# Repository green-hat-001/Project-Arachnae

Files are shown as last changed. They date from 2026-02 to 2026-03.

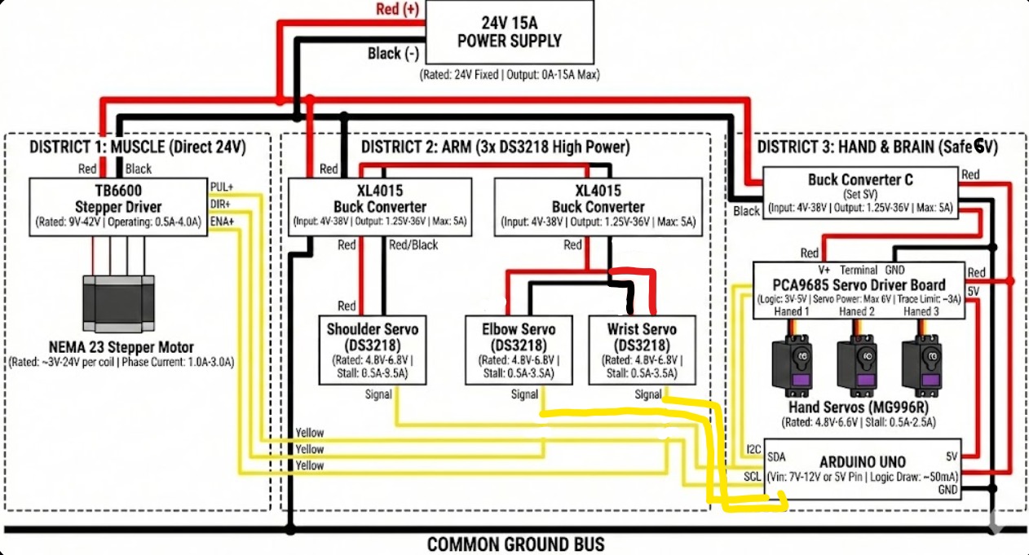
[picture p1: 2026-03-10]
Schematic.jpeg

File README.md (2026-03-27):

# Project-Arachnae
A semi-opensource prosthetic aimed at making prosthetics more usable and accessable to people with a tight budget and/or in developing countries. This project was started as passion project to experiment on a freind of mine who doesn't have an arm. Then as the project developed it became a vision to make these prosthetic more accessable and more usable compared to the super expensive ones out there that dont really have much functionalty built into them. 

The main step file has been compressed due to its size of CAD model. Below is the link to veiw the file in the browser as again the file is way too big to upload to github. You can download .f3d or any other file types from the below link.
-> https://a360.co/4daP7HM

**How to use:**
- The user will wear a backplate that houses the arm. When the user turns on the arm a preloaded script automatically runs. Then the user can voice out commands like, "Top right cup" and the ML model built into the arm will use the camera mounted on the hand to search for a cup in the "top right" of the user. The camera also serves as a method for the hand to determine the optimal grip for the object.

- 1770411682987 (1)

The below will explain how the arm works, for greater detail contact me via the email (gal1le02620@gmail.com)

---

## How It Works: Technical Architecture

Project Arachnae leverages accessible hardware and software to create a highly functional, low-cost bionic arm. The system is broken down into three main categories: mechanical design, hardware, and the control system.

### 1. Mechanical Design & Manufacturing

To keep costs low and ensure the prosthetic is accessible globally, the structural components are fully 3D printable. 
* **Modeling:** The components are designed using CAD software like Fusion 360 and OpenSCAD. 
* **Fabrication:** Parts can be printed using standard, widely available filaments. Because the main CAD models (like the compressed STEP file mentioned above) are provided, users can modify the design to fit specific anatomical dimensions or hardware availability.

### 2. Hardware & Actuation
The physical movement of the arm relies on a hybrid motor setup designed to balance heavy lifting power with fine motor control:
* **Stepper Motor:** A NEMA 23 stepper motor is utilized for the joints requiring higher torque and structural stability. 
* **Servos:** Micro-servos actuate the finer movements, driving the tension systems that allow the individual fingers to flex and extend. 3xDS3218 are used to move each arm segments. However, V2 will house a ST3215 for better feedback and controllability and much higher torque ceilings. These servos are assisted through gravity compensation.

### 3. Electronics & Software Control
The "brain" of Project Arachnae uses a combination of high-level programming and low-level microcontroller execution:
* **Microcontroller:** An Arduino serves as the hardware interface. It is responsible for sending precise electrical signals to the motor drivers.
* **Logic & Processing
g:** Python runs in tandem with the Arduino to handle the heavier logic, process user inputs, and dictate the overall state of the arm.
* **Safety & Calibration:** To protect both the user and the 3D-printed mechanisms, the control code features a soft-start routine. The software explicitly prevents the servos from jumping violently to a default position upon startup, ensuring smooth, safe initialization. This will be improved in V2 thanks to a feature of the ST3215 that allows the user to read its angle at all times. 

### 4. BOM
## Bill of Materials (BOM)

| Item | Quantity | Description / Purpose | Link |
| :--- | :---: | :--- | :--- |
| DS3218 20kg Servo | 3 | High-torque servos for primary high-tension movements (e.g. main grip/wrist) | [Buy](https://www.amazon.ae/Miuzei-Torque-Waterproof-Control-Digital/dp/B0CQX9SYP2/ref=sr_1_5) |
| MG996R Pro Servo | 3 | Standard-torque metal gear servos for secondary finger articulation | [Buy](https://www.amazon.ae/Deegoo-4-Pack-MG996R-Digital-Helicopter/dp/B07MFK266B/ref=sr_1_2) |
| NEMA 23 Stepper Motor | 1 | High-torque motor for the main structural load-bearing joint | [Buy](https://www.amazon.ae/STEPPERONLINE-Stepper-Motor-339-79oz-57x57x82mm/dp/B091C37FJ2/ref=sr_1_3) |
| Arduino Uno (or Clone) | 1 | Main microcontroller for processing logic and sending motor signals | [Buy](https://www.amazon.ae/Arduino-bridges-high-performance-computing-real-time/dp/B0GFN669S4/ref=sr_1_16) |
| TB6600 Stepper Motor Driver | 1 | Required to safely deliver high current to the NEMA 23 | [Buy](https://www.amazon.ae/Usongshine-Stepper-Driver-Controller-Motor%EF%BC%881/dp/B07HHS14VQ/ref=sr_1_3) |
| 12V or 24V Power Supply | 1 | High-wattage wall adapter or PSU to power the stepper motor | [Buy](https://www.amazon.ae/Switching-Regulated-Transformer-Converter-Computer/dp/B09X9R9668/ref=sr_1_8) |
| 5V DC-DC Buck Converter | 3–4 | Steps down 12V/24V to a safe 5V for the servos (do not power servos directly from Arduino) | [Buy](https://www.amazon.ae/1-25-36V-Step-Down-Converter-Voltage-Regulator/dp/B0F24ZHB4S/ref=sr_1_3) |
| Long Strong Rubber Bands | 1 roll | Used as high-tension tendons for finger actuation | [Buy](https://www.amazon.ae/Kowvowz-Large-Rubber-Bands-Approximately/dp/B0CQ7F6KJS/ref=sr_1_37) |
| Jumper Wires & Perfboard | 1 set | For routing signals between the Arduino, driver, and servos | Local store (~30 AED) |
| M3 / M4 Screws & Nuts | 1 kit | Standard metric hardware for assembling the 3D printed chassis | Local store (~25 AED) |
| 3D Printer Filament (PLA+/PETG) | 3 kg | Main structural material — PLA+ or PETG recommended for durability | [Buy](https://www.amazon.ae/ELEGOO-Filament-Black-Dimensional-1kg/dp/B0F7LBXB2X/ref=sr_1_1_sspa) |

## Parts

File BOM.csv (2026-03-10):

Item | Quantity | Description / Purpose | Link / Estimated Cost (USD)
DS3218 20kg Servo | 3 | High-torque servos for primary high-tension movements (e.g. main grip/wrist) | https://www.amazon.ae/Miuzei-Torque-Waterproof-Control-Digital/dp/B0CQX9SYP2/ref=sr_1_5
MG996R Pro Servo | 3 | Standard-torque metal gear servos for secondary finger articulation | https://www.amazon.ae/Deegoo-4-Pack-MG996R-Digital-Helicopter/dp/B07MFK266B/ref=sr_1_2
NEMA 23 Stepper Motor | 1 | High-torque motor for the main structural load-bearing joint | https://www.amazon.ae/STEPPERONLINE-Stepper-Motor-339-79oz-57x57x82mm/dp/B091C37FJ2/ref=sr_1_3
Arduino Uno (or Clone) | 1 | The main microcontroller for processing logic and sending motor signals | https://www.amazon.ae/Arduino-bridges-high-performance-computing-real-time/dp/B0GFN669S4/ref=sr_1_16
TB6600 Stepper Motor Driver | 1 | Required to safely deliver high current to the NEMA 23 | https://www.amazon.ae/Usongshine-Stepper-Driver-Controller-Motor%EF%BC%881/dp/B07HHS14VQ/ref=sr_1_3
12V or 24V Power Supply | 1 | High-wattage wall adapter or PSU to power the stepper motor | https://www.amazon.ae/Switching-Regulated-Transformer-Converter-Computer/dp/B09X9R9668/ref=sr_1_8
5V DC-DC Buck Converter | 3-4 | Steps down the 12V/24V power to a safe 5V for the 6 servos (do not power servos directly from Arduino) | https://www.amazon.ae/1-25-36V-Step-Down-Converter-Voltage-Regulator/dp/B0F24ZHB4S/ref=sr_1_3
Long Strong Rubber Bands | 1 Roll | Used as high-tension tendons for finger actuation | https://www.amazon.ae/Kowvowz-Large-Rubber-Bands-Approximately/dp/B0CQ7F6KJS/ref=sr_1_37
Jumper Wires & Perfboard | 1 Set | For routing signals between the Arduino / driver / and servos | Bought from local store (~30 AED)
M3 / M4 Screws & Nuts | 1 Kit | Standard metric hardware for assembling the 3D printed chassis | Bought from local store (~25 AED)
3D Printer Filament | 3 kg | PLA+ or PETG recommended for durability and ease of printing | https://www.amazon.ae/ELEGOO-Filament-Black-Dimensional-1kg/dp/B0F7LBXB2X/ref=sr_1_1_sspa

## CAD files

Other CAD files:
Base V3.step
Base V3.f3z

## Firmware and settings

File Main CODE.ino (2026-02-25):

// #include <WiFiS3.h>
// #include <Wire.h>
// #include <Adafruit_PWMServoDriver.h>
// #include <AccelStepper.h>
// #include <ArduinoGraphics.h> 
// #include "Arduino_LED_Matrix.h"
// #include "arduino_secrets.h"

// // --- PCA9685 PIN MAPPING ---
// #define S_SHOULDER 0  // DS3218 (High Torque)
// #define S_WRIST_J  1  // DS3218 (Wrist Pivot)
// #define S_FOREARM  2  // DS3218 (Elbow)

// #define CH_THUMB   4  // MG996R
// #define CH_ROT_W   5  // MG996R (Wrist Rotate)
// #define CH_INDEX   6  // MG996R

// // --- STEPPER CONFIG ---
// #define STEPPER_PUL_PIN 3
// #define STEPPER_DIR_PIN 2

// // --- CALIBRATION ---
// #define USMIN  100 
// #define USMAX  580 
// const int SPEED = 5; 

// Adafruit_PWMServoDriver pwm = Adafruit_PWMServoDriver();
// AccelStepper baseStepper(AccelStepper::DRIVER, STEPPER_PUL_PIN, STEPPER_DIR_PIN);
// ArduinoLEDMatrix matrix;
// WiFiServer server(80);

// char ssid[] = SECRET_SSID;
// char pass[] = SECRET_PASS;

// // --- STATE TRACKING ---
// int angIndex = 0, angThumb = 60, angRotW = 0; 
// int angS = 90, angF = 90, angWJ = 90;         
// int lastP_Idx = 100, lastP_Thm = 266, lastP_Rot = 100;

// void setup() {
//   Serial.begin(115200);
//   delay(1500); 
//   Serial.println("\n--- PROJECT ARACHNAE STARTING ---");

//   pwm.begin();
//   pwm.setPWMFreq(50);
//   matrix.begin();

//   baseStepper.setMaxSpeed(1500);
//   baseStepper.setAcceleration(800);

//   Serial.print("Connecting to WiFi...");
//   WiFi.begin(ssid, pass); 
//   while (WiFi.status() != WL_CONNECTED) {
//     delay(500);
//     Serial.print(".");
//   }

//   server.begin();
//   Serial.println("\nConnected! IP: ");
//   Serial.println(WiFi.localIP());
  
//   displayIP(WiFi.localIP());

//   // Initialize all joints
//   syncHand(0, 60, 0); 
//   updateArm();
// }

// void loop() {
//   baseStepper.run(); 

//   // 1. Listen for Python AI (Serial)
//   if (Serial.available()) {
//     String cmd = Serial.readStringUntil('\n');
//     cmd.trim();
//     Serial.print("Serial Cmd: "); Serial.println(cmd);
//     processCommand(cmd);
//   }

//   // 2. Listen for Web Control (WiFi)
//   WiFiClient client = server.available();
//   if (client) {
//     String request = "";
//     while (client.connected() && client.available()) {
//       char c = client.read();
//       if (c == '\n') break;
//       request += c;
//     }
//     if (request.indexOf("/G") != -1) processCommand("G");
//     if (request.indexOf("/R") != -1) processCommand("R");
    
//     sendHTML(client);
//     client.stop();
//   }
// }

// void processCommand(String cmd) {
//   // GRIPPER
//   if (cmd == "G") syncHand(180, 60, 180);      
//   else if (cmd == "R") syncHand(0, 60, 0);     
  
//   // BASE
//   else if (cmd == "B_LEFT") baseStepper.move(-400);
//   else if (cmd == "B_RIGHT") baseStepper.move(400);

//   // ARM SEGMENTS
//   else if (cmd == "S+") { angS = constrain(angS + 10, 0, 180); updateArm(); }
//   else if (cmd == "S-") { angS = constrain(angS - 10, 0, 180); updateArm(); }
//   else if (cmd == "F+") { angF = constrain(angF + 10, 0, 180); updateArm(); }
//   else if (cmd == "F-") { angF = constrain(angF - 10, 0, 180); updateArm(); }
//   else if (cmd == "W+") { angWJ = constrain(angWJ + 10, 0, 180); updateArm(); }
//   else if (cmd == "W-") { angWJ = constrain(angWJ - 10, 0, 180); updateArm(); }
// }

// void syncHand(int tIdx, int tThm, int tRot) {
//   int pIdx = map(tIdx, 0, 180, USMIN, USMAX);
//   int pThm = map(tThm, 0, 180, USMIN, USMAX);
//   int pRot = map(tRot, 0, 180, USMIN, USMAX);

//   while (lastP_Idx != pIdx || lastP_Thm != pThm || lastP_Rot != pRot) {
//     if (lastP_Idx < pIdx) lastP_Idx++; else if (lastP_Idx > pIdx) lastP_Idx--;
//     if (lastP_Thm < pThm) lastP_Thm++; else if (lastP_Thm > pThm) lastP_Thm--;
//     if (lastP_Rot < pRot) lastP_Rot++; else if (lastP_Rot > pRot) lastP_Rot--;

//     pwm.setPWM(CH_INDEX, 0, lastP_Idx);
//     pwm.setPWM(CH_THUMB, 0, lastP_Thm);
//     pwm.setPWM(CH_ROT_W, 0, lastP_Rot);
//     delay(SPEED);
//     baseStepper.run(); 
//   }
//   angIndex = tIdx; angThumb = tThm; angRotW = tRot;
// }

// void updateArm() {
//   // Reverse logic applied to shoulder (USMAX to USMIN)
//   pwm.setPWM(S_SHOULDER, 0, map(angS, 0, 180, USMAX, USMIN)); 
//   pwm.setPWM(S_FOREARM, 0, map(angF, 0, 180, USMIN, USMAX));
//   pwm.setPWM(S_WRIST_J, 0, map(angWJ, 0, 180, USMIN, USMAX));
// }

// void sendHTML(WiFiClient c) {
//   c.println("HTTP/1.1 200 OK\nContent-Type: text/html\n");
//   c.print("<html><head><meta name='viewport' content='width=device-width, initial-scale=1'></head>");
//   c.print("<body style='text-align:center; font-family:sans-serif;'><h1>Project Arachnae</h1>");
//   c.print("<a href='/G'><button style='padding:30px; width:90%; background:red; color:white; font-size:20px;'>GRIP</button></a><br><br>");
//   c.print("<a href='/R'><button style='padding:30px; width:90%; background:green; color:white; font-size:20px;'>RELEASE</button></a>");
//   c.print("</body></html>");
// }

// void displayIP(IPAddress ip) {
//   String ipStr = "  " + ip.toString() + "  ";
//   matrix.beginDraw();
//   matrix.stroke(0xFFFFFFFF);
//   matrix.textScrollSpeed(60);
//   matrix.textFont(Font_5x7);
//   matrix.beginText(0, 1, 0xFFFFFFFF);
//   matrix.println(ipStr);
//   matrix.endText(SCROLL_LEFT);
//   matrix.endDraw();
// }



#include <Wire.h>
#include <Adafruit_PWMServoDriver.h>
#include <AccelStepper.h>

// --- PCA9685 PIN MAPPING ---
// Arm Segments (DS3218)
#define S_SHOULDER 0  
#define S_WRIST_J  1  
#define S_ELBOW    2  // CHANGED NAME TO MATCH PYTHON

// Hand/Gripper (MG996R)
#define CH_THUMB   4  
#define CH_ROT_W   5  
#define CH_INDEX   6  

// --- STEPPER CONFIG ---
#define STEPPER_PUL_PIN 3
#define STEPPER_DIR_PIN 2

// --- CALIBRATION ---
#define USMIN  100 
#define USMAX  580 
const int SPEED = 5; 

Adafruit_PWMServoDriver pwm = Adafruit_PWMServoDriver();
AccelStepper baseStepper(AccelStepper::DRIVER, STEPPER_PUL_PIN, STEPPER_DIR_PIN);

// --- STATE TRACKING ---
int angIndex = 0, angThumb = 60, angRotW = 0; 
int angS = 90, angE = 90, angWJ = 90; // CHANGED angF -> angE
int lastP_Idx = 100, lastP_Thm = 266, lastP_Rot = 100;

void setup() {
  Serial.begin(115200); 
  
  pwm.begin();
  pwm.setPWMFreq(50);

  baseStepper.setMaxSpeed(1500);
  baseStepper.setAcceleration(800);

  // Initialize to Neutral Position
  syncHand(0, 60, 0); 
  updateArm();
  
  Serial.println("--- ARACHNAE WIRED SYSTEM READY ---");
  Serial.println("Commands: G/R (Hand), S+/S- (Shoulder), E+/E- (Elbow), W+/W- (WristJ)");
}

void loop() {
  baseStepper.run(); 

  if (Serial.available() > 0) {
    String cmd = Serial.readStringUntil('\n');
    cmd.trim(); 
    processCommand(cmd);
  }
}

void processCommand(String cmd) {
  // DEBUG: Print what we received to prove Python is talking to us
  // Serial.print("RECEIVED: "); Serial.println(cmd);

  // --- GRIPPER COMMANDS ---
  if (cmd == "G") syncHand(180, 60, 180);      
  else if (cmd == "R") syncHand(0, 60, 0);     
  
  // --- BASE STEPPER COMMANDS ---
  else if (cmd == "B_LEFT") baseStepper.move(-400);
  else if (cmd == "B_RIGHT") baseStepper.move(400);

  // --- ARM SEGMENT COMMANDS ---
  // SHOULDER
  else if (cmd == "S+") { 
    angS = constrain(angS + 5, 0, 180); 
    updateArm(); 
    Serial.print("Shoulder: "); Serial.println(angS);
  }
  else if (cmd == "S-") { 
    angS = constrain(angS - 5, 0, 180); 
    updateArm(); 
    Serial.print("Shoulder: "); Serial.println(angS);
  }

  // ELBOW (Formerly Forearm) - Fixed to listen for "E"
  else if (cmd == "E+") { 
    angE = constrain(angE + 5, 0, 180); 
    updateArm(); 
    Serial.print("Elbow: "); Serial.println(angE);
  }
  else if (cmd == "E-") { 
    angE = constrain(angE - 5, 0, 180); 
    updateArm(); 
    Serial.print("Elbow: "); Serial.println(angE);
  }

  // WRIST JOINT
  else if (cmd == "W+") { 
    angWJ = constrain(angWJ + 5, 0, 180); 
    updateArm(); 
    Serial.print("WristJ: "); Serial.println(angWJ);
  }
  else if (cmd == "W-") { 
    angWJ = constrain(angWJ - 5, 0, 180); 
    updateArm(); 
    Serial.print("WristJ: "); Serial.println(angWJ);
  }
}

void syncHand(int tIdx, int tThm, int tRot) {
  int pIdx = map(tIdx, 0, 180, USMIN, USMAX);
  int pThm = map(tThm, 0, 180, USMIN, USMAX);
  int pRot = map(tRot, 0, 180, USMIN, USMAX);

  while (lastP_Idx != pIdx || lastP_Thm != pThm || lastP_Rot != pRot) {
    if (lastP_Idx < pIdx) lastP_Idx++; else if (lastP_Idx > pIdx) lastP_Idx--;
    if (lastP_Thm < pThm) lastP_Thm++; else if (lastP_Thm > pThm) lastP_Thm--;
    if (lastP_Rot < pRot) lastP_Rot++; else if (lastP_Rot > pRot) lastP_Rot--;

    pwm.setPWM(CH_INDEX, 0, lastP_Idx);
    pwm.setPWM(CH_THUMB, 0, lastP_Thm);
    pwm.setPWM(CH_ROT_W, 0, lastP_Rot);
    delay(SPEED);
    baseStepper.run(); 
  }
  angIndex = tIdx; angThumb = tThm; angRotW = tRot;
}

void updateArm() {
  // Pin 0: Shoulder | Pin 1: Wrist Joint | Pin 2: Elbow
  pwm.setPWM(S_SHOULDER, 0, map(angS, 0, 180, USMAX, USMIN)); // Reversed?
  pwm.setPWM(S_WRIST_J, 0, map(angWJ, 0, 180, USMIN, USMAX));
  pwm.setPWM(S_ELBOW,   0, map(angE, 0, 180, USMIN, USMAX));
}

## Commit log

2026-02-26 Rename Project arachnae.zip to Project arachnae CAD.zip
2026-03-10 Update README with usage instructions and safety info
    Added usage instructions for the arm and improved safety details.
2026-03-10 Add Bill of Materials section to README
    Added a Bill of Materials (BOM) section detailing components required for the project, including item descriptions and purchase links.
2026-04-07 Add CAD models using Git LFS
    [Base V3.f3z, Base V3.step]
